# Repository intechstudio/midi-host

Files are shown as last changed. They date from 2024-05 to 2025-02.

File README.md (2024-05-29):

## Electrical components

| Component | Part number | Preview | Links |
|---|---|---|---|
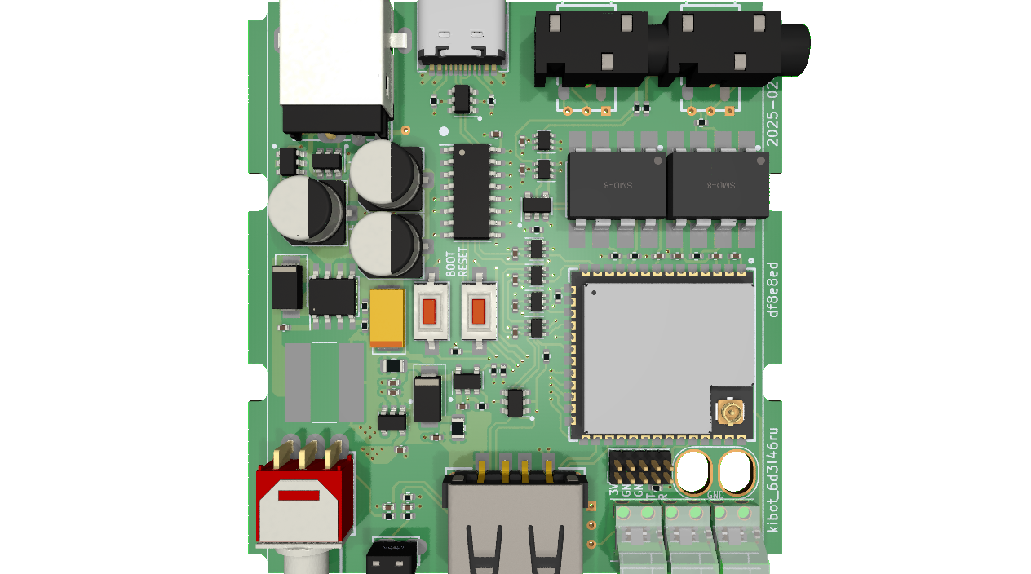
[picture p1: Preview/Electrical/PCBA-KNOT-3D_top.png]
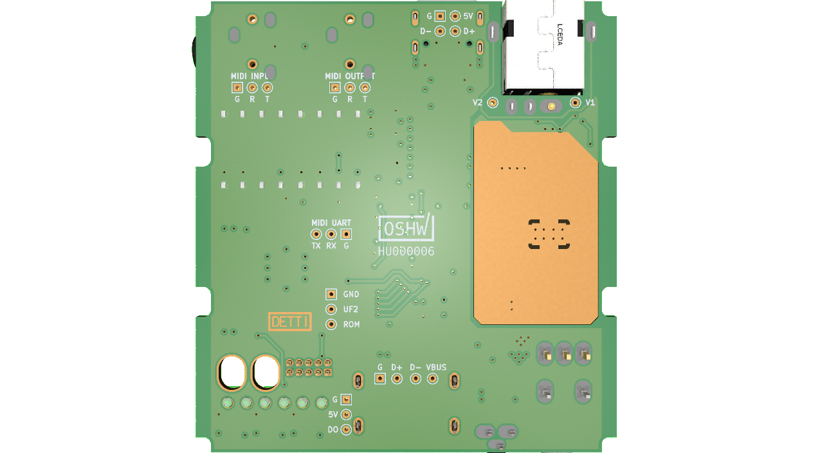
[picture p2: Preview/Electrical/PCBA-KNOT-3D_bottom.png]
| KNOT board | PCBA-KNOT |   | [[Schematic]](Preview/Electrical/PCBA-KNOT_Schematic.pdf) [[STEP]](Preview/Electrical/PCBA-KNOT-3D.step?raw=true) [[Gerber]](Preview/Electrical/mfg/PCBA-KNOT-gerber.zip?raw=true)  [[PCB3D]](Preview/Electrical/PCBA-KNOT-blender_export.pcb3d?raw=true)  |

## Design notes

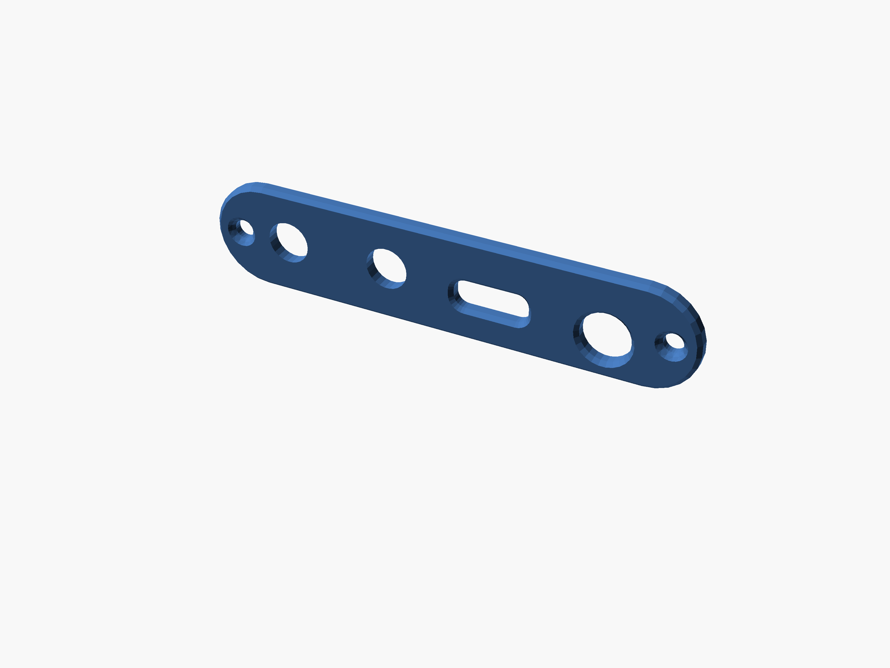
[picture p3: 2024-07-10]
Preview/Mechanical/KNOT-BACK.png

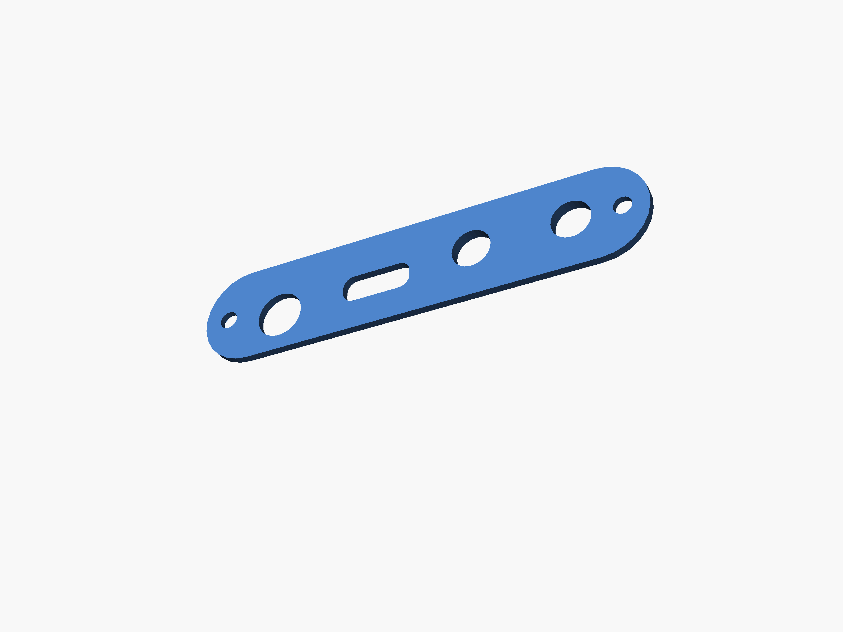
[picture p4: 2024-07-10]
Preview/Mechanical/KNOT-BACK_reverse.png

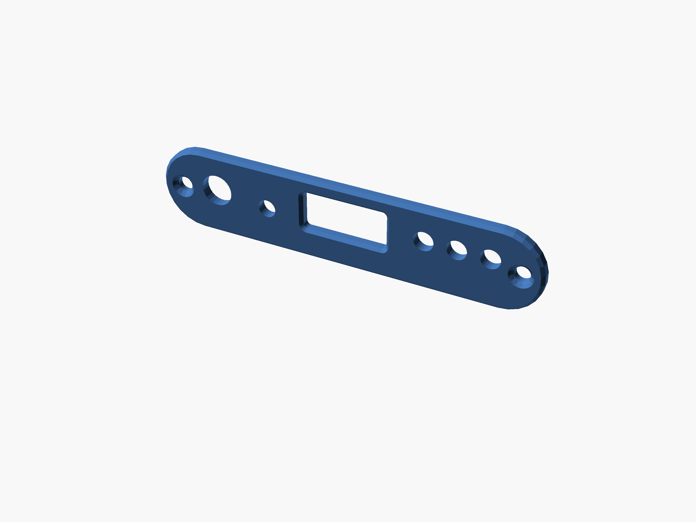
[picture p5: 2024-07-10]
Preview/Mechanical/KNOT-FRONT.png

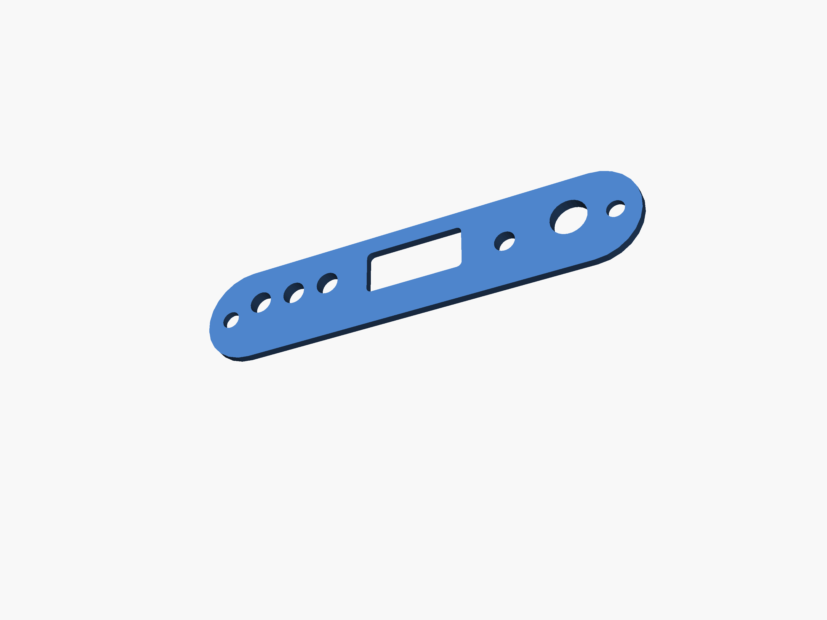
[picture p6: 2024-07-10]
Preview/Mechanical/KNOT-FRONT_reverse.png

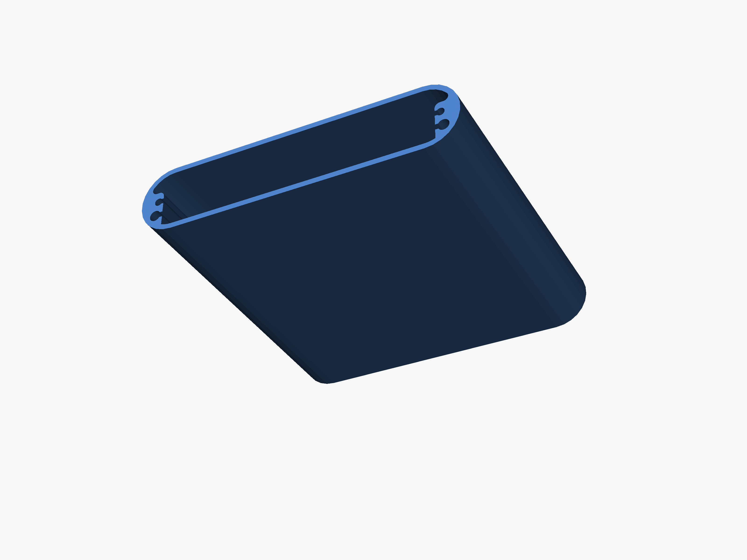
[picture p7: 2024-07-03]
Preview/Mechanical/KNOT-HOUSING_reverse.png

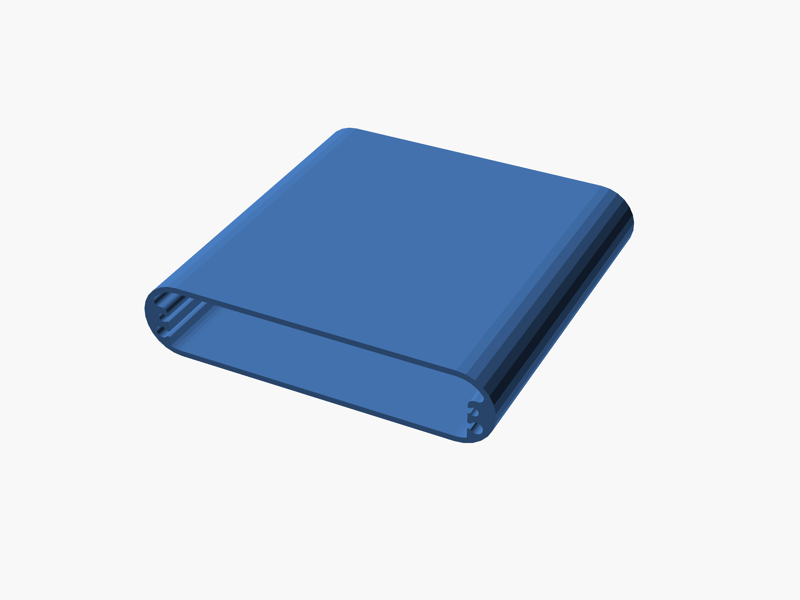
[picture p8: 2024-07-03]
Preview/Mechanical/KNOT-HOUSING.png

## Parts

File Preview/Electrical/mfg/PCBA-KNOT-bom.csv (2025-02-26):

Qty | Designator | Part | Comment | Footprint
2 | Audio1,Audio2 | PJ-320B | AUDIO-TH_PJ-3200 | AUDIO-TH_PJ-3200
1 | C21 | CAP | 10n | CAP_0402
15 | C3,C4,C5,C6,C7,C8,C9,C11,C12,C13,C14,C15,C16,C26,C27 | CAP | 100n | CAP_0402
2 | C1,C22 | CAP | 1u | CAP_0402
3 | C2,C20,C25 | CAP | 10u | CAP_0402
1 | C24 | CAP_POL | CA45-C6R3K337T | CP_EIA-6032-15_Kemet-U
3 | C17,C18,C19 | CAP_POL | CS1E470M-CRE54 | CP_Elec_6.3x5.7
1 | CN1 | USB-CON-AF-LCP-Offset | C42567 | USB-A-SMD_AF-APPLE-10.6
2 | D4,D5 | SCHOTTKY | B340LA-13-F | D_SMA
3 | D1,D2,D3 | UI_WS2812C-2020 | UI_WS2812C-2020 | UI_WS2812C-2020_LIGHTPIPE
1 | DC1 | DC-C033D-5.5A-2.0 | DC-C033D-5.5A-2.0 | DC-IN-TH_DC-C033D-5.5A-2.0
2 | FB1,FB2 | FERRIT | MPZ2012S101AT000 | FERRIT_0805
1 | J3 | Conn_01x02 | Conn_01x02 | OscilloscopeGround
1 | J1 | USB_C_TYPE-C-32-M-12 | TYPE-C-32-M-12 | USB_C_Korean_Hroparts_TYPE-C-31-M-12
1 | L1 | INDUCTOR | SNR.8065.TYD220MT00 | L_Bourns-SRN8040_8x8.15mm
1 | LOGO1 | OSHWA | OSHWA | OSHWA_KNOT
1 | Q1 | Q_DUAL_PMOS_G1S2G2D2S1D1-Device | WST2011 | SOT-23-6
1 | Q2 | Q_Dual_NMOS_G1S2G2D2S1D1 | WST3392 | SOT-23-6
3 | R13,R14,R15 | RES | 220R | RES_0402
4 | R5,R8,R9,R12 | RES | 1k | RES_0402
2 | R22,R23 | RES | 3k3 | RES_0402
7 | R6,R7,R10,R11,R16,R17,R18 | RES | 5k1 | RES_0402
4 | R1,R2,R20,R21 | RES | 10k | RES_0402
2 | SW1,SW2 | SW_SPST | C2905169 | SW_SPST_CK_RS282G05A3
1 | SW4 | ST-0-102-C03-N003-RS | ST-0-102-C03-N003-RS | SW-TH_ST-0-102-C03-N003-RS
1 | SW3 | TC-1109DE-C-G | TC-1109DE-C-G | SW-TH_3P-L4.5-W7.0-P3.00-LS1.9
2 | U12,U13 | 6N137 | 6N137 | OPTO_SMD-8_L9.8-W6.6-P2.54-LS10.3-BL
1 | U8 | 74HC165 | 74HC165 | SOIC-16_74HC165
1 | U14 | 74HC1G14GV | 74HC1G14GV | SOT-23-5-AND-TSSOP5
6 | U2,U3,U4,U5,U10,U11 | BL1551B | BL1551B | SOT-363_SC-70-6
1 | U1 | ESP32-S3-WROOM-1U | ESP32-S3-WROOM-1U | ESP32-S3-WROOM-1U
1 | U17 | U_REGULATOR_SOT23-5 | LN1134A332MR-G | SOT-23-5
1 | U16 | PMIC_MT9700 | PMIC_MT9700 | SOT-23-5
3 | U6,U7,U9 | U_ESD_4ch | SESRV05-4 | SOT-23-6
1 | U15 | TPS5430DDA | TPS5430DDA | TI_SO-PowerPAD-8_ThermalVias

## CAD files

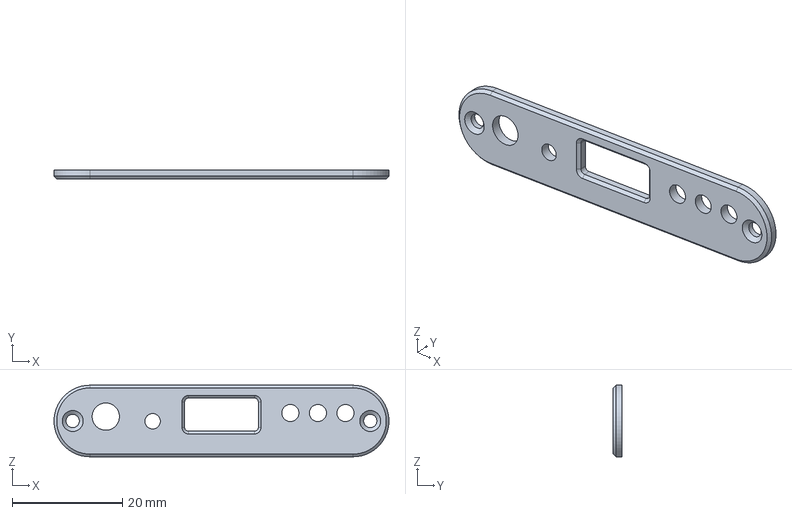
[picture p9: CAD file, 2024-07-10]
Preview/Mechanical/KNOT-FRONT.step
60.8 x 1.60 x 13.0 mm

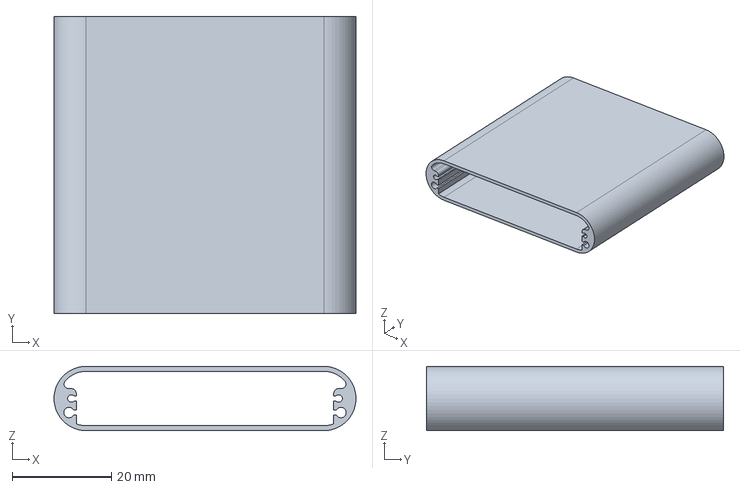
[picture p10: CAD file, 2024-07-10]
Preview/Mechanical/KNOT-HOUSING.step
61.0 x 60.0 x 13.0 mm

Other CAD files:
Preview/Mechanical/KNOT-BACK.step
Preview/Mechanical/KNOT-BACK.stl
Preview/Mechanical/KNOT-FRONT.stl
Preview/Mechanical/KNOT-HOUSING.stl

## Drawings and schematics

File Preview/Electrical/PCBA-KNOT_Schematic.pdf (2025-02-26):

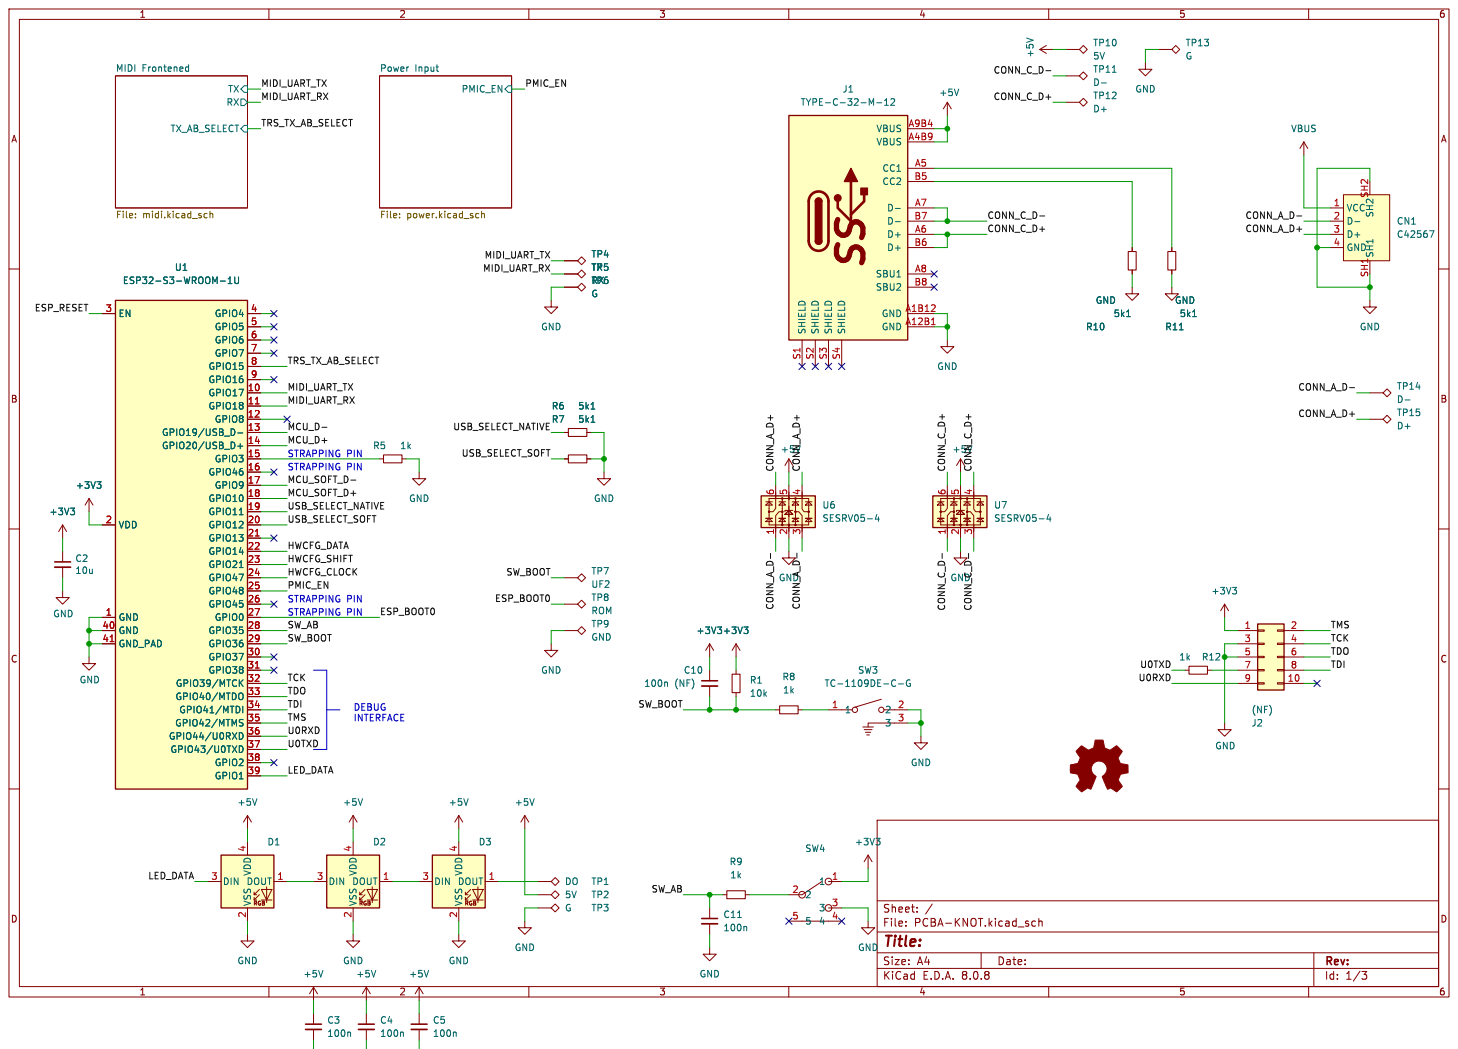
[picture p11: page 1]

Power Input File: power.kicad_sch

Id: 1/3 Title: File: PCBA-KNOT.kicad_sch Sheet: /

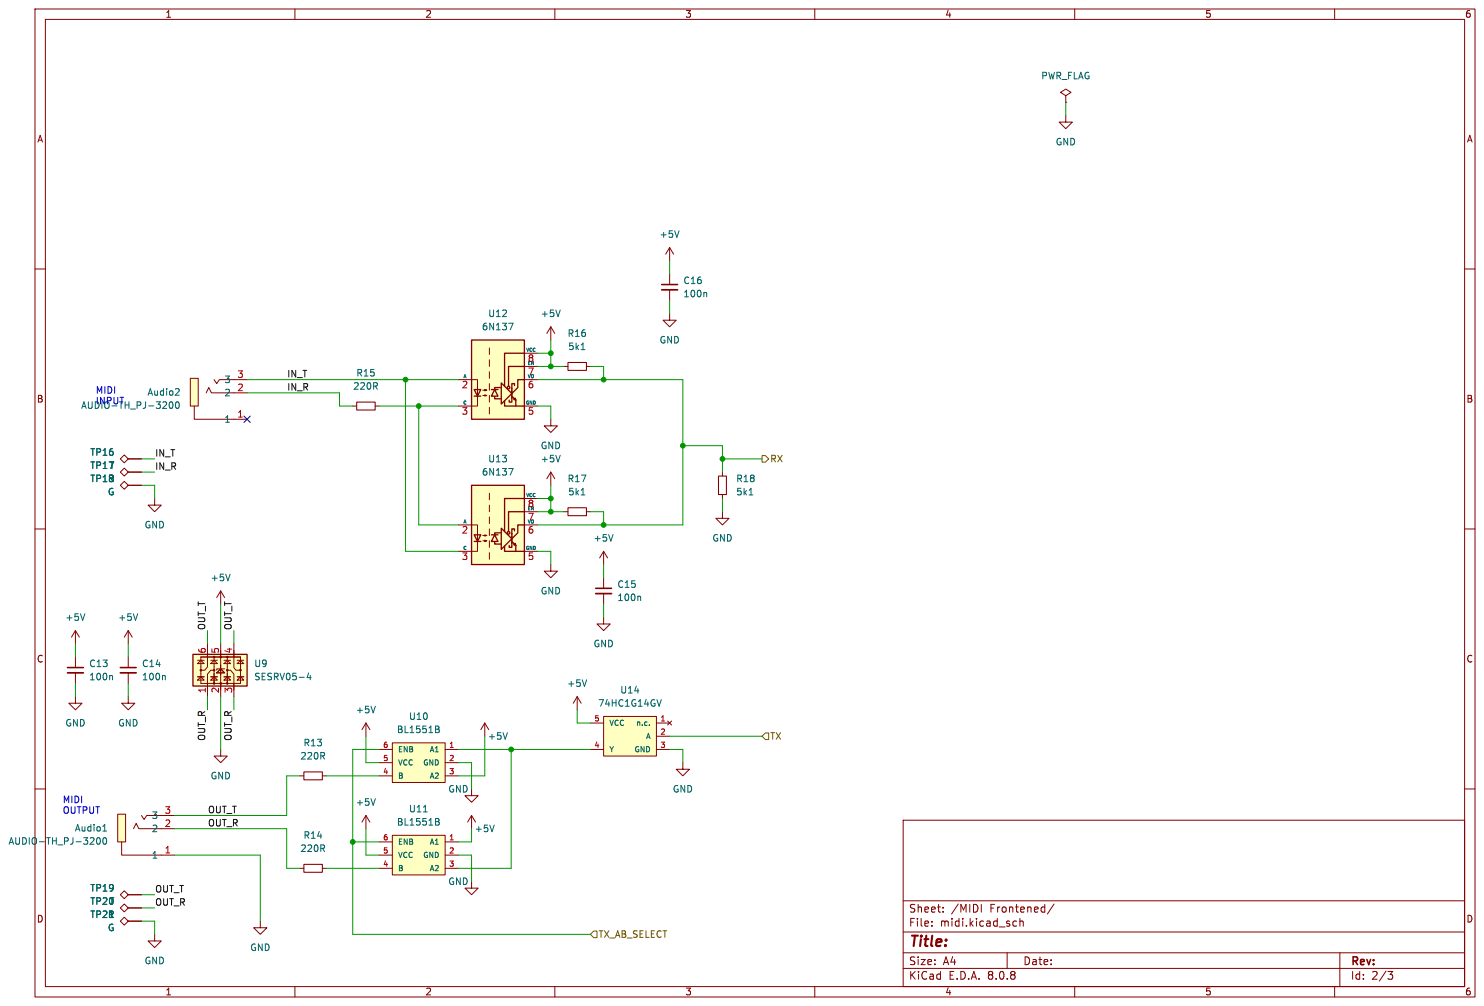
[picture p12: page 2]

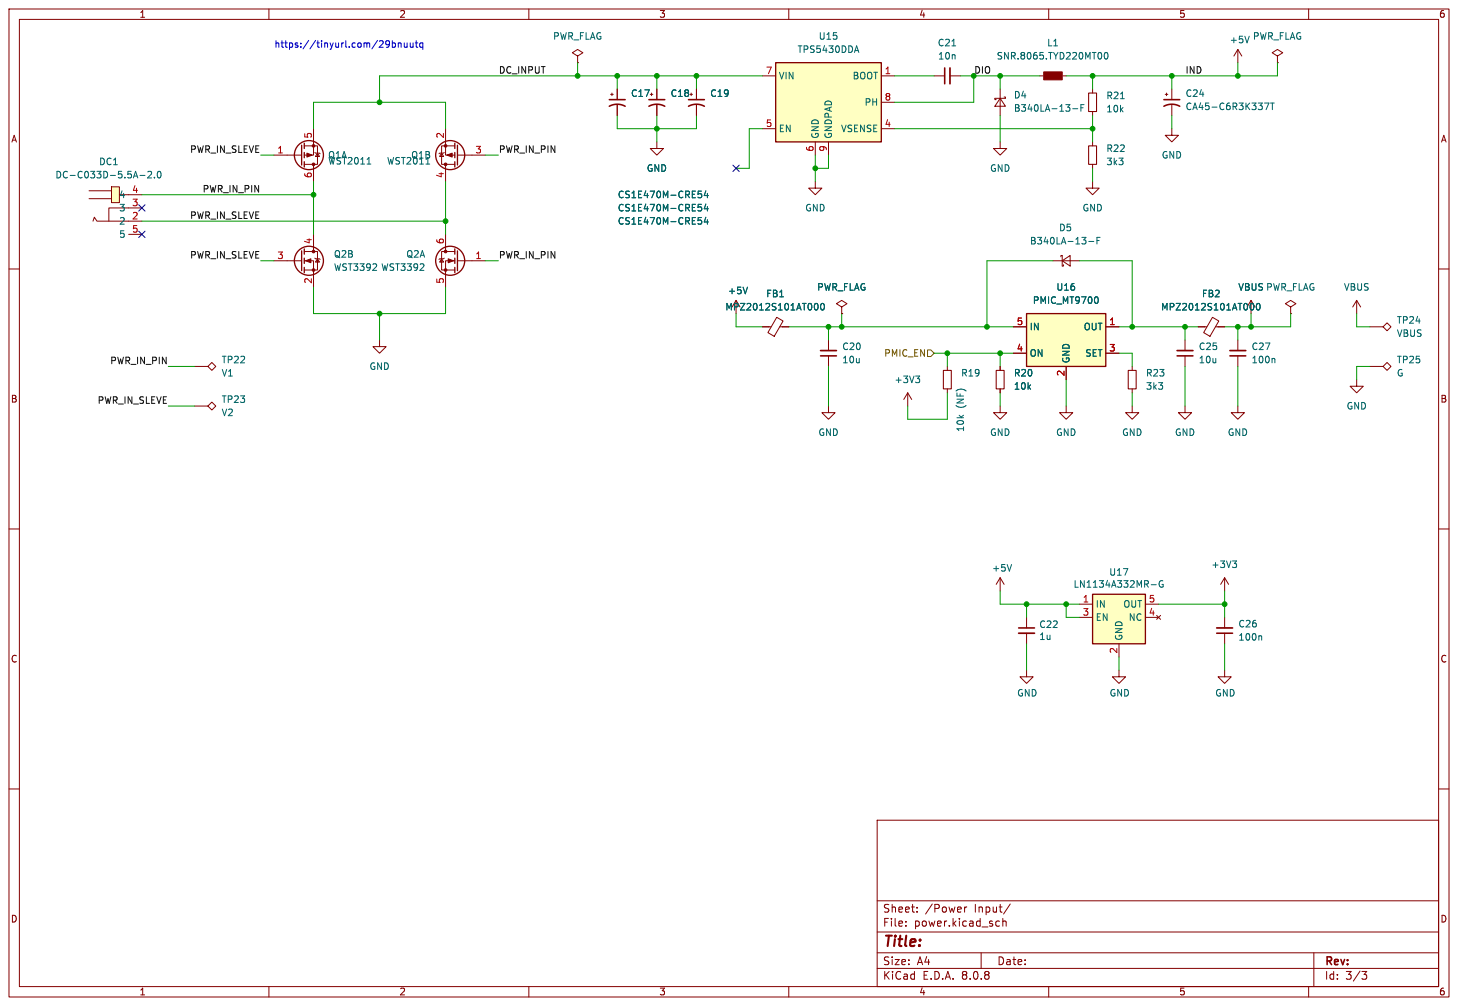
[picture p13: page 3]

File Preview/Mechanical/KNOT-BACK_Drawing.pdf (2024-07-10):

2× ⌀5.2 ± 0.05

- 0,1

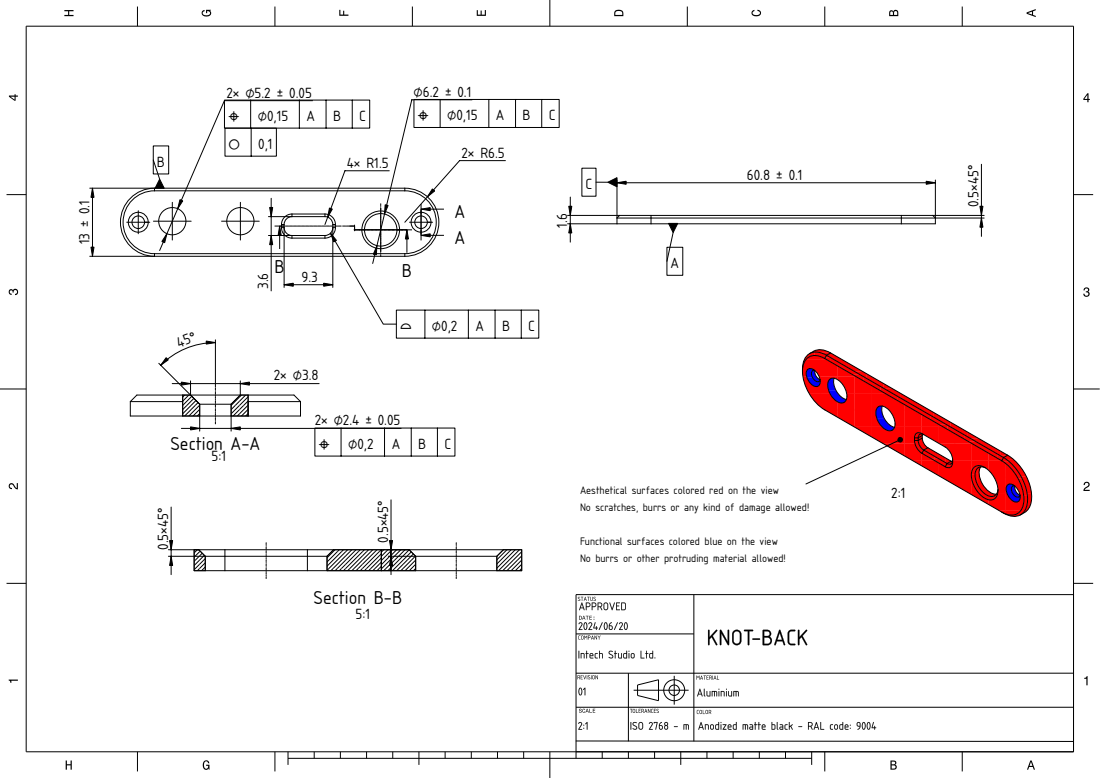
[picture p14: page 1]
Section A-A; Section B-B

Aesthetical surfaces colored red on the view
No scratches, burrs or any kind of damage allowed!

Functional surfaces colored blue on the view
No burrs or other protruding material allowed!

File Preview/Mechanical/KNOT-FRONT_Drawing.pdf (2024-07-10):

⌀4.95 ± 0.05
⌖ | ⌀0,15 | A | B | C

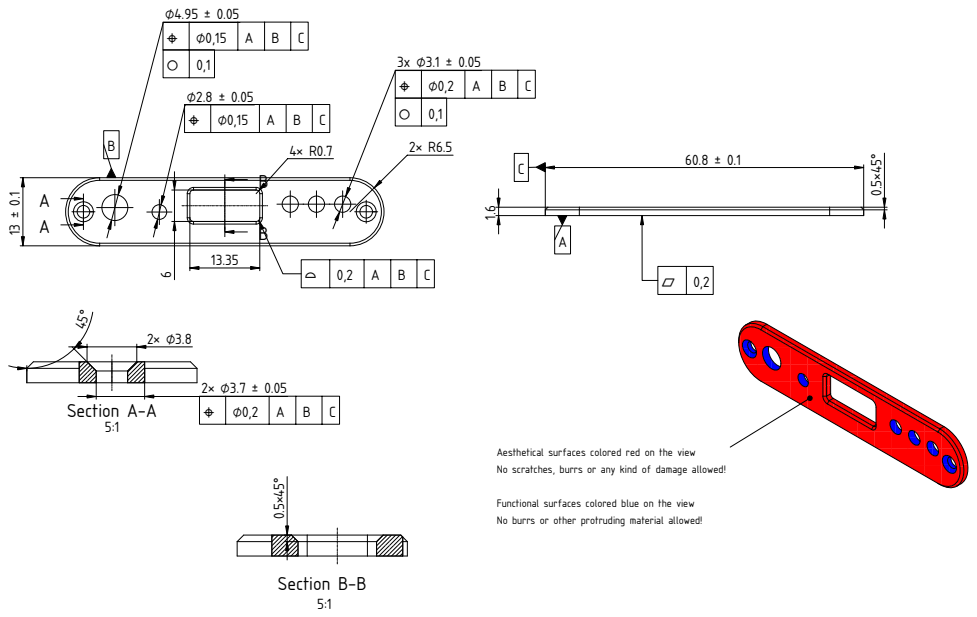
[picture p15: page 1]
Section A-A; Section B-B

⌖ | ⌀0,2 | A | B | C
○ 0,1

Aesthetical surfaces colored red on the view
No scratches, burrs or any kind of damage allowed!

Functional surfaces colored blue on the view
No burrs or other protruding material allowed!

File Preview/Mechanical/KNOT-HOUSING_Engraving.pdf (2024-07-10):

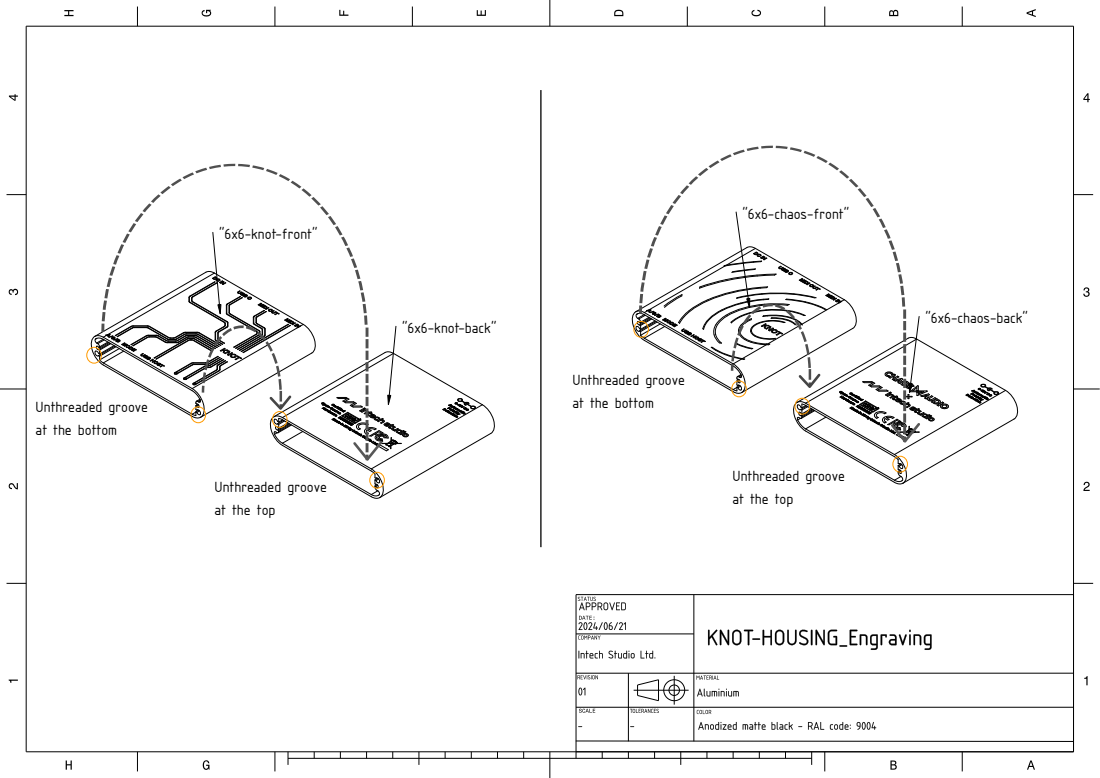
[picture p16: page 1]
"6x6-chaos-front"; "6x6-chaos-back"; "6x6-knot-front"; "6x6-knot-back"

Unthreaded groove
at the bottom

at the top

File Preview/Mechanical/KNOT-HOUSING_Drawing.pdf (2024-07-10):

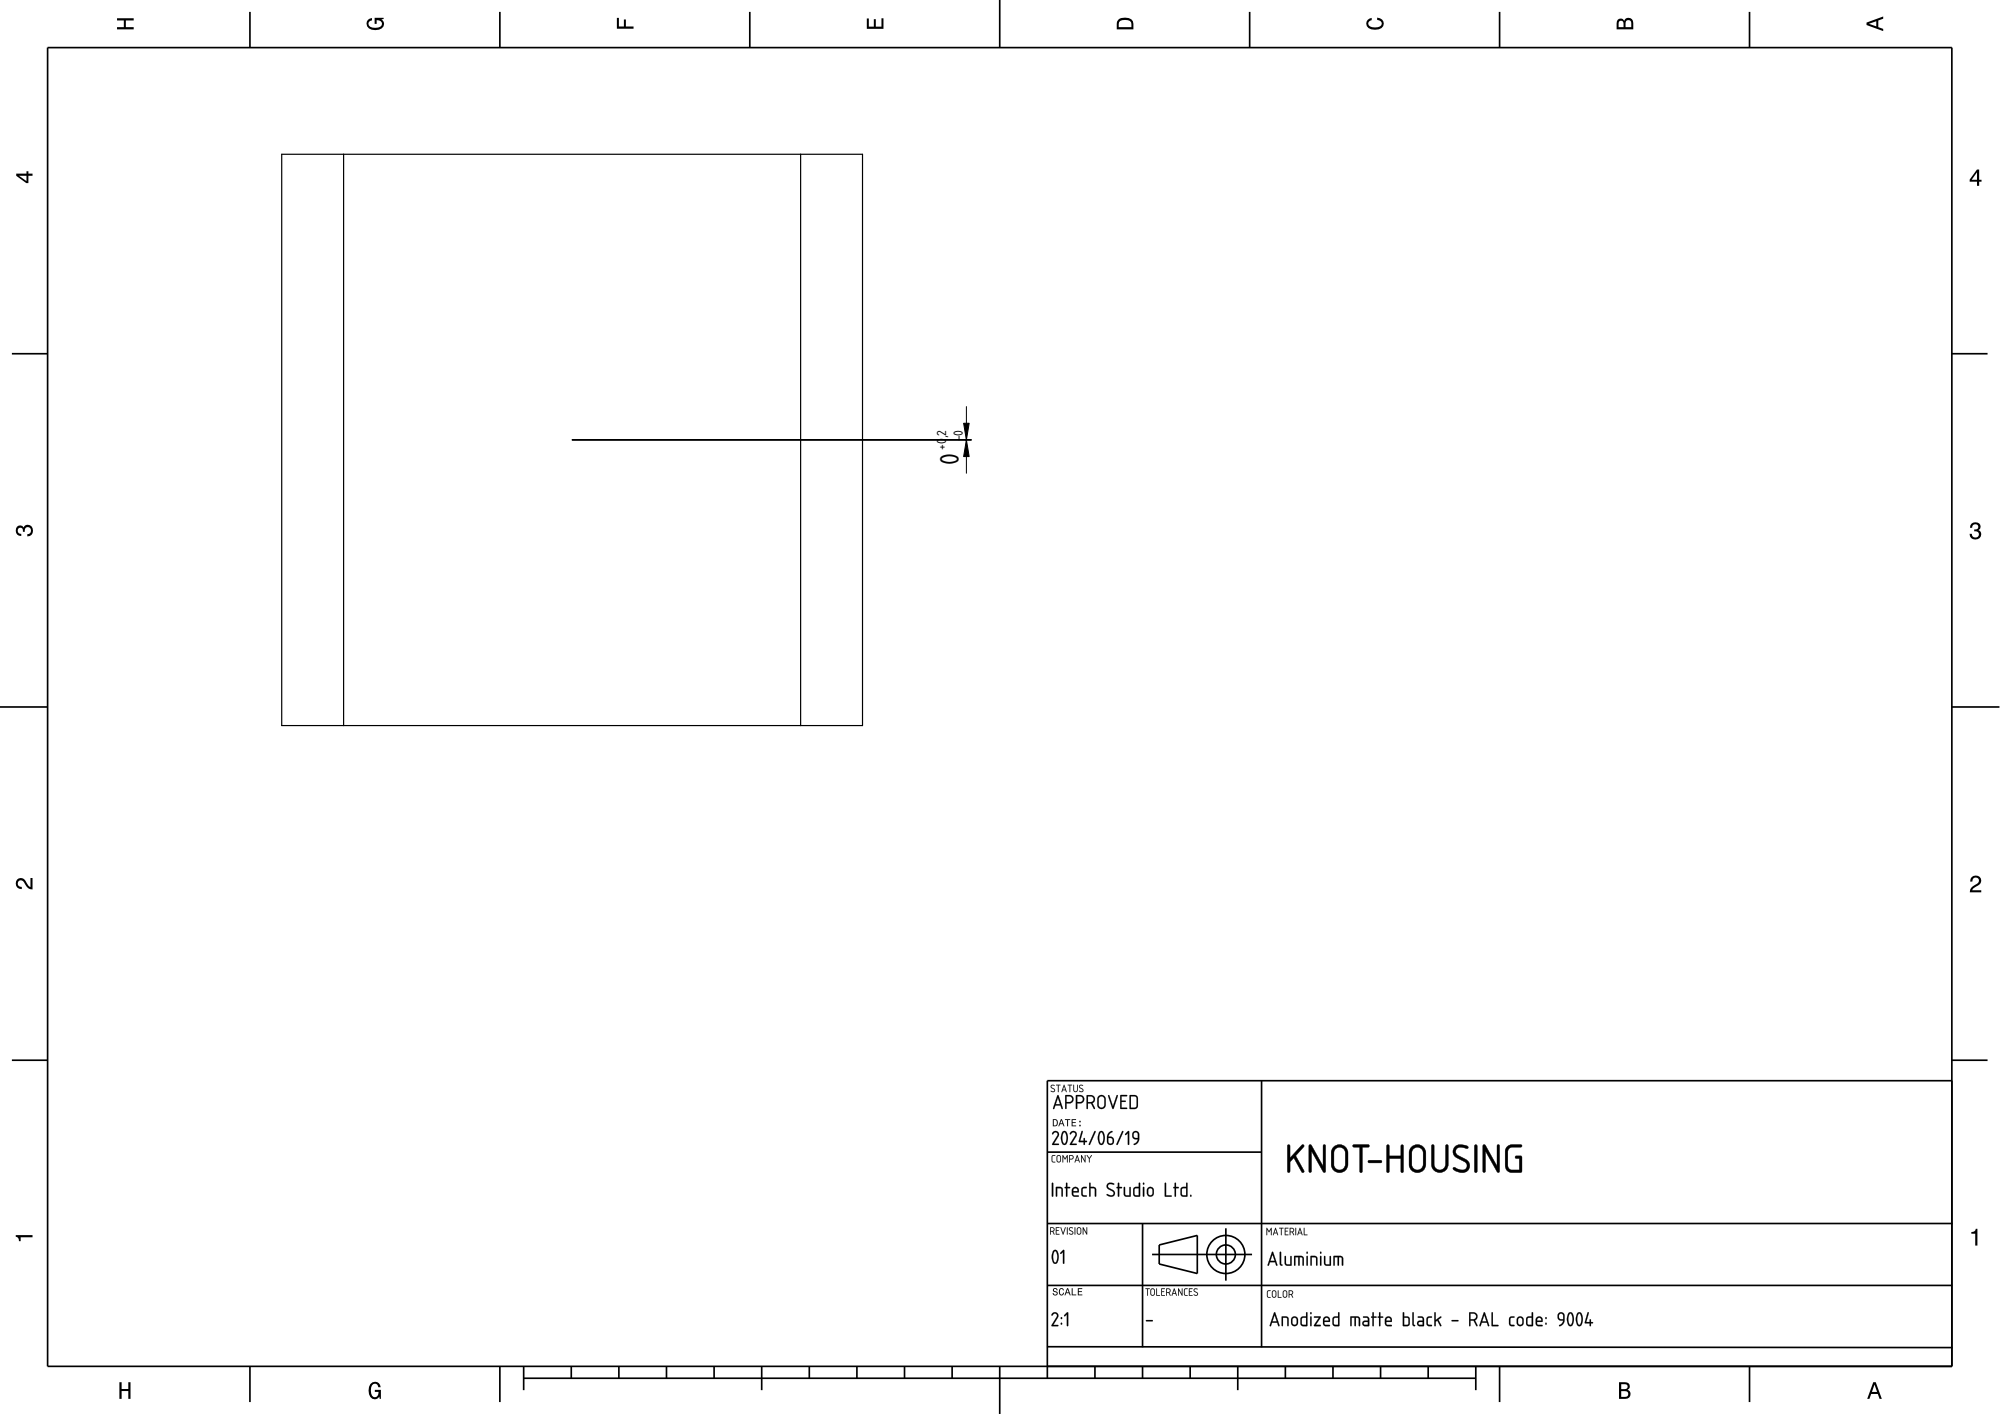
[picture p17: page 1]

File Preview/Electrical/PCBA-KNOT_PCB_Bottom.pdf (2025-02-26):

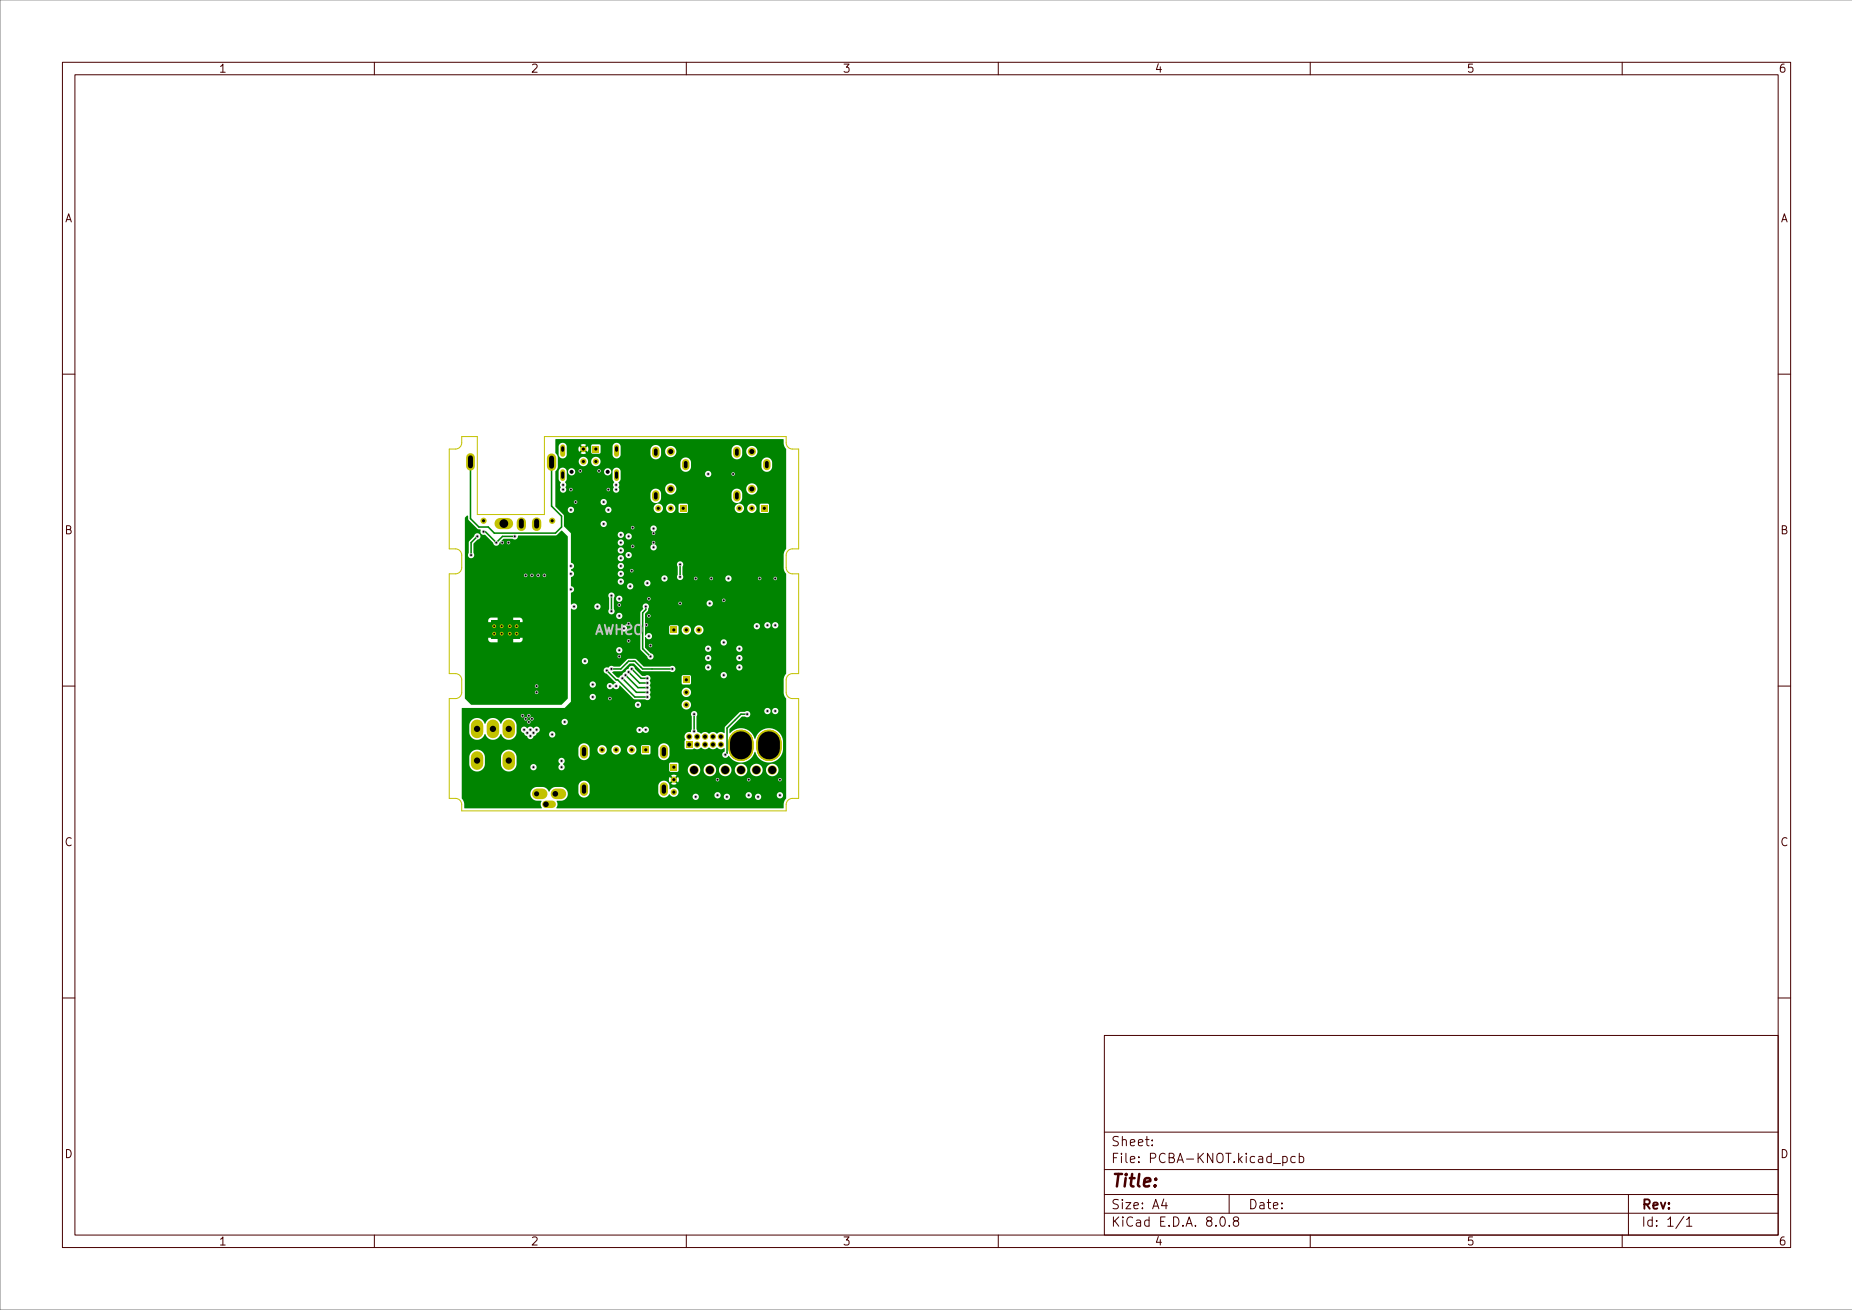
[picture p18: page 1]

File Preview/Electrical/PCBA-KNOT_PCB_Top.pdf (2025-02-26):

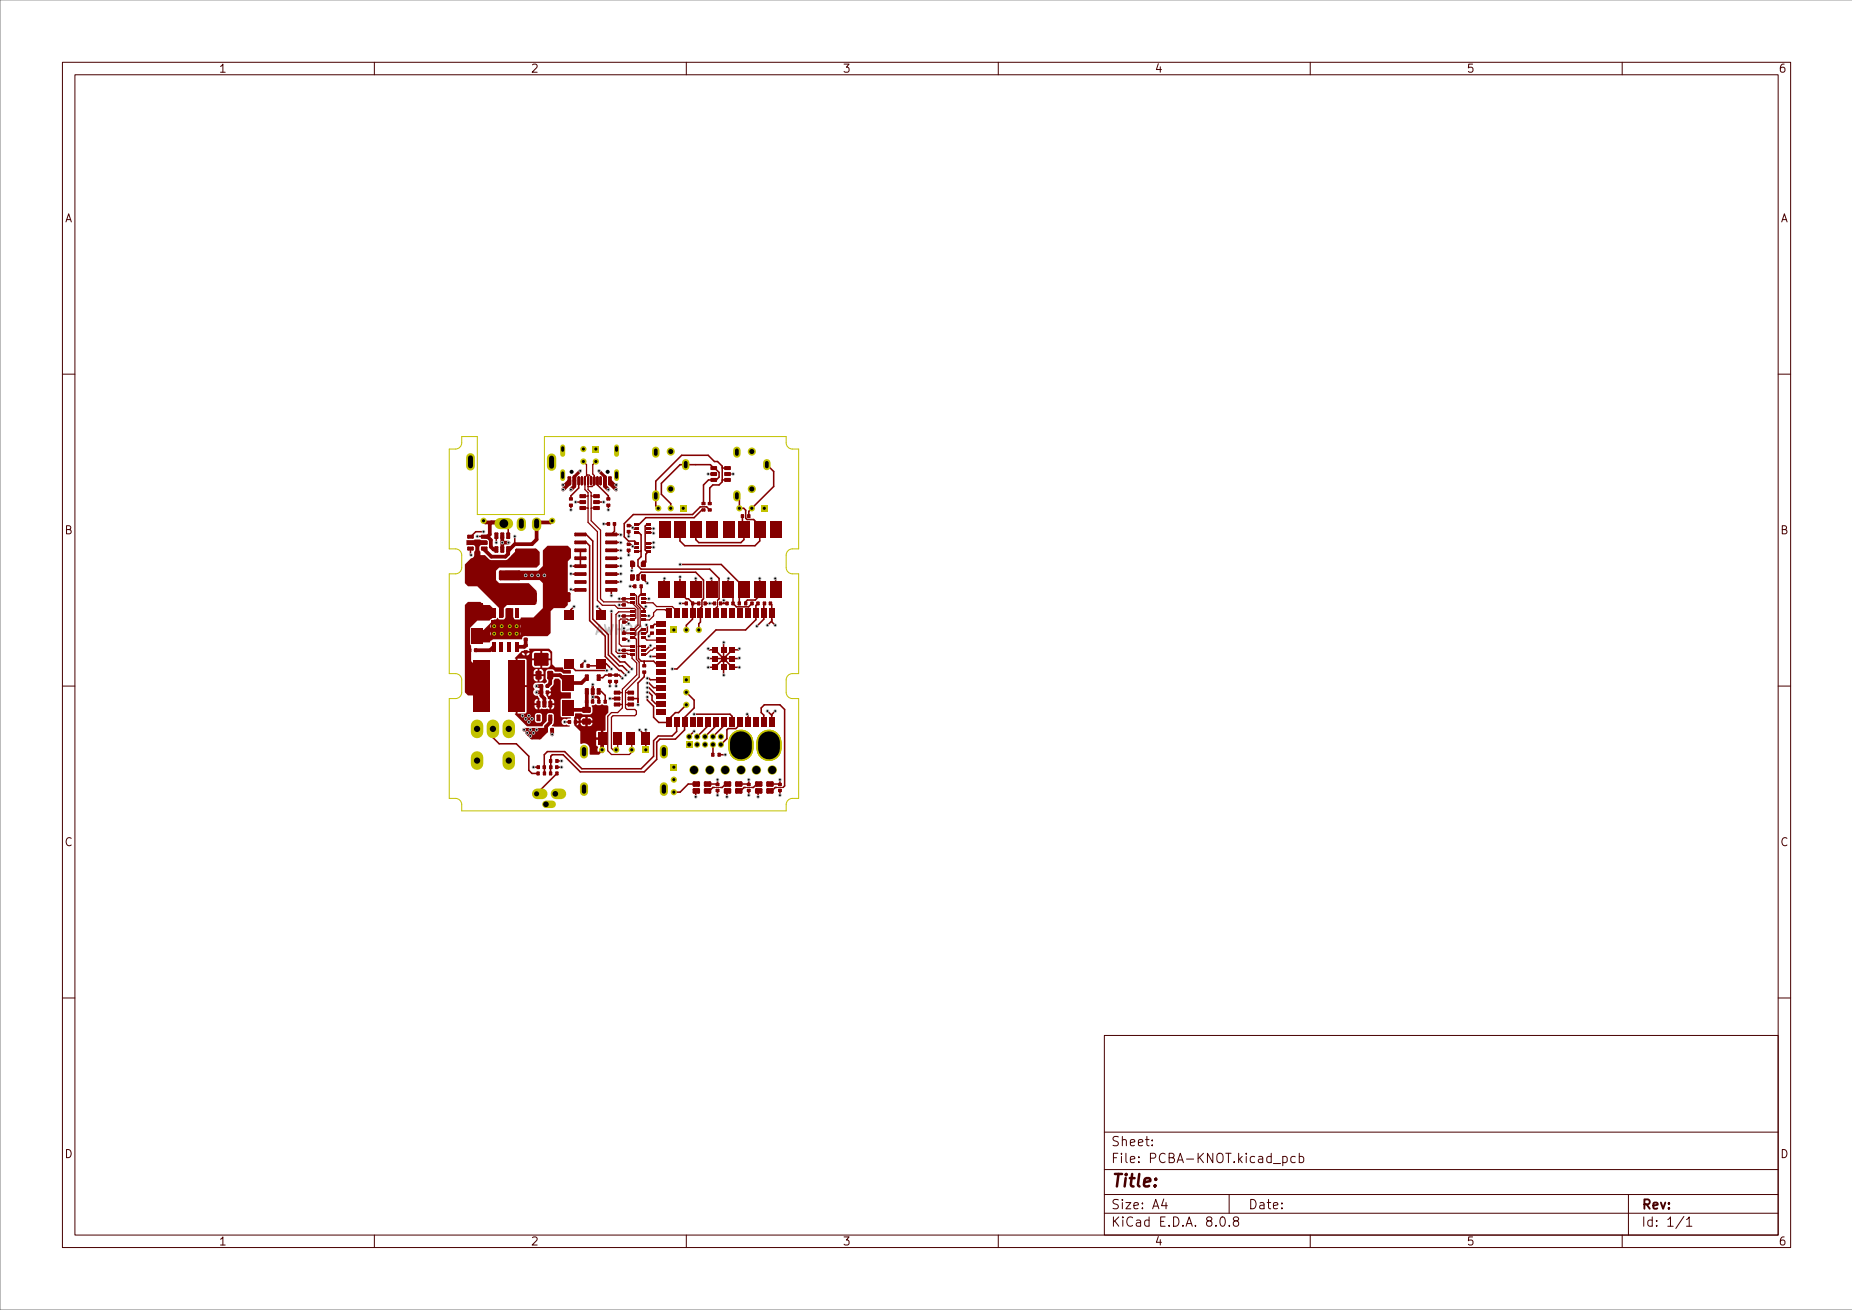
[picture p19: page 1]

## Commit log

2024-01-08 BOT electrical_boards c38b5f6118388d4c4f2382671c39b19b8cd62608
    [PCBA-KNOT-bom.csv, PCBA-KNOT-both_pos_fixed.csv]
2024-05-07 BOT electrical_boards 385a1d80c5ba1312efd466ba64479cc8c8c7454b
    [PCBA-KNOT-both_pos_fixed.csv]
2024-05-28 BOT electrical_boards a3478a81246c979e519dbcd1d8f5742e75229971
    [PCBA-KNOT-bom.csv, PCBA-KNOT-both_pos_fixed.csv]
2024-07-01 BOT electrical_boards d0d9dcaaabe4a12d755ef583e0f033c27be3a144
    [PCBA-KNOT-both_pos_fixed.csv]
2024-07-03 BOT mechanical_components 59eef8adb33b73da57b478a27181a805b6b26565
    [KNOT-BACK.step, KNOT-BACK.stl, KNOT-FRONT.step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]
2024-07-03 BOT mechanical_components c675dcdf18825794db3a37b6d4829e8c09927482
    [KNOT-BACK.step, KNOT-FRONT.step, KNOT-HOUSING.step]
2024-07-05 BOT mechanical_components 89d4b0c036863530e244ff5c07b8a69181fae14d
    [KNOT-BACK.step, KNOT-FRONT.step, KNOT-HOUSING.step]
2024-07-10 BOT mechanical_components a67d9f3b6c4ccccecfcd8ccf2508a92495802cfd
    [KNOT-BACK.step, KNOT-BACK.stl, KNOT-FRONT.step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]
2025-02-26 BOT electrical_boards 96f49515d0cbd4ba9909b8dde66af47e3c58cb11
    [PCBA-KNOT-bom.csv, PCBA-KNOT-both_pos_fixed.csv]
